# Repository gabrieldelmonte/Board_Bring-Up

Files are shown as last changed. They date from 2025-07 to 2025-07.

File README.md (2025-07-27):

# Board Bring-Up Project

A microcontroller-based embedded system project featuring real-time monitoring, alarm management, and multi-language support using the PIC18F4550 microcontroller.

## Project Overview

This project implements a comprehensive board bring-up system that combines multiple peripherals and sensors to create a monitoring and control system. The system features a state machine-based architecture with real-time clock functionality, analog sensor monitoring, alarm management, and a user-friendly LCD interface.

## Features

### Core Functionality
- **Real-Time Clock (RTC)**: DS1307-based timekeeping with hour, minute, and second setting
- **Analog Monitoring**: ADC-based sensor reading with configurable alarm thresholds
- **Alarm System**: Dual-level alarm monitoring (high/low thresholds) with visual indicators
- **Multi-Language Support**: Interface available in 6 different languages
- **State Machine Architecture**: Robust navigation system between different operational modes

### Hardware Peripherals
- **LCD Display**: 16-character display for system information and menus
- **LED Control**: Visual feedback and alarm indication system
- **Button Interface**: Navigation and parameter adjustment controls
- **I2C Communication**: For RTC and DAC communication
- **PWM Output**: Pulse width modulation for analog output control
- **Serial Communication**: UART interface for debugging and external communication
- **DAC Output**: MCP4725-based digital-to-analog conversion

### System States
- **Menu**: Main navigation interface
- **Alarm Configuration**: Set high and low alarm thresholds
- **Language Selection**: Choose from 6 available languages
- **Time Setting**: Configure hours, minutes, and seconds
- **Warning Mode**: Alert state when alarm conditions are triggered

## Hardware Requirements

### Microcontroller
- **PIC18F4550** microcontroller
- **20 MHz** crystal oscillator
- Power supply and basic support components

### Peripherals
- **DS1307** Real-Time Clock module
- **MCP4725** Digital-to-Analog Converter
- **16x2 LCD Display** with HD44780 controller
- **LEDs** for status indication
- **Push buttons** for user interface
- **Analog sensor** (connected to ADC channel 0)

### Development Tools
- MPLAB X IDE or compatible PIC development environment
- XC8 compiler for PIC18 family
- Programmer/debugger (PICkit, ICD, etc.)

## Project Structure

```
Board_Bring-Up/
├── src/
│   ├── main.c              # Main application entry point
│   └── code/
│       ├── ADC.c           # Analog-to-Digital Converter functions
│       ├── button.c        # Button handling and debouncing
│       ├── DAC_MCP4725.c   # MCP4725 DAC communication
│       ├── delay.c         # Timing and delay functions
│       ├── event.c         # Event handling and system events
│       ├── I2C.c           # I2C communication protocol
│       ├── LCD.c           # LCD display control functions
│       ├── LED.c           # LED control and patterns
│       ├── output.c        # Output formatting and display
│       ├── PWM.c           # Pulse Width Modulation control
│       ├── RTC_DS1307.c    # Real-Time Clock functions
│       ├── serial.c        # UART serial communication
│       ├── stateMachine.c  # Main state machine implementation
│       ├── variables.c     # Global variable management
│       └── headers/        # Header files for all modules
├── hardware/               # KiCad PCB design files
├── diagrams/               # System architecture diagrams
└── docs/                   # Project documentation
```

## Getting Started

### Prerequisites
1. MPLAB X IDE installed
2. XC8 compiler for PIC18 family
3. PIC programmer/debugger
4. Assembled hardware board or prototyping setup

### Building the Project
1. Clone this repository:
   ```bash
   git clone https://github.com/your-username/Board_Bring-Up.git
   cd Board_Bring-Up
   ```

2. Open the project in MPLAB X IDE

3. Configure the project settings:
   - Select PIC18F4550 as target device
   - Set XC8 as the compiler
   - Configure programmer/debugger

4. Build the project:
   - Click "Build" or use Ctrl+F11
   - Resolve any compilation errors

5. Program the microcontroller:
   - Connect your programmer
   - Click "Make and Program Device"

### Hardware Setup
1. Connect the LCD display to PORTD and control pins (RA2, RA3)
2. Wire the DS1307 RTC to the I2C bus (RC3/SCL, RC4/SDA)
3. Connect analog sensor to AN0 (RA0)
4. Wire push buttons for navigation
5. Connect LEDs for status indication
6. Ensure proper power supply (5V for PIC18F4550)

## Usage

### Navigation
- **Base Button**: Return to main menu from any state
- **Left/Right Buttons**: Navigate between menu options
- **Up/Down Buttons**: Adjust values in configuration modes

### Setting Alarms
1. Navigate to alarm configuration states
2. Use up/down buttons to adjust high and low thresholds
3. System will trigger warnings when sensor readings exceed limits

### Time Configuration
1. Access time setting modes through menu navigation
2. Adjust hours, minutes, and seconds individually
3. Changes are automatically saved to RTC

### Language Selection
- Navigate to language menu
- Choose from 6 available language options
- Interface will update to selected language

## Configuration

### System Parameters
Key configuration options in `defines.h`:
- `FREQ`: System frequency (20 MHz)
- `NUMBER_LANGUAGES`: Available languages (6)
- `MAX_ADC_VALUE`: Maximum ADC reading (1000)
- `MIN_ADC_VALUE`: Minimum ADC reading (0)

### Pin Assignments
- **LCD Data**: PORTD (RD0-RD7)
- **LCD Control**: RA2 (RS), RA3 (EN)
- **I2C**: RC3 (SCL), RC4 (SDA)
- **ADC Input**: RA0 (AN0)
- **LED Outputs**: Configurable in LED.c

## Additional Resources

- [PIC18F4550 Datasheet](https://www.microchip.com/en-us/product/PIC18F4550)
- [DS1307 RTC Datasheet](https://datasheets.maximintegrated.com/en/ds/DS1307.pdf)
- [MCP4725 DAC Datasheet](https://ww1.microchip.com/downloads/en/DeviceDoc/22039d.pdf)
- PCB design files are available in the `hardware/` directory

## License

This project is licensed under the terms specified in the LICENSE file.

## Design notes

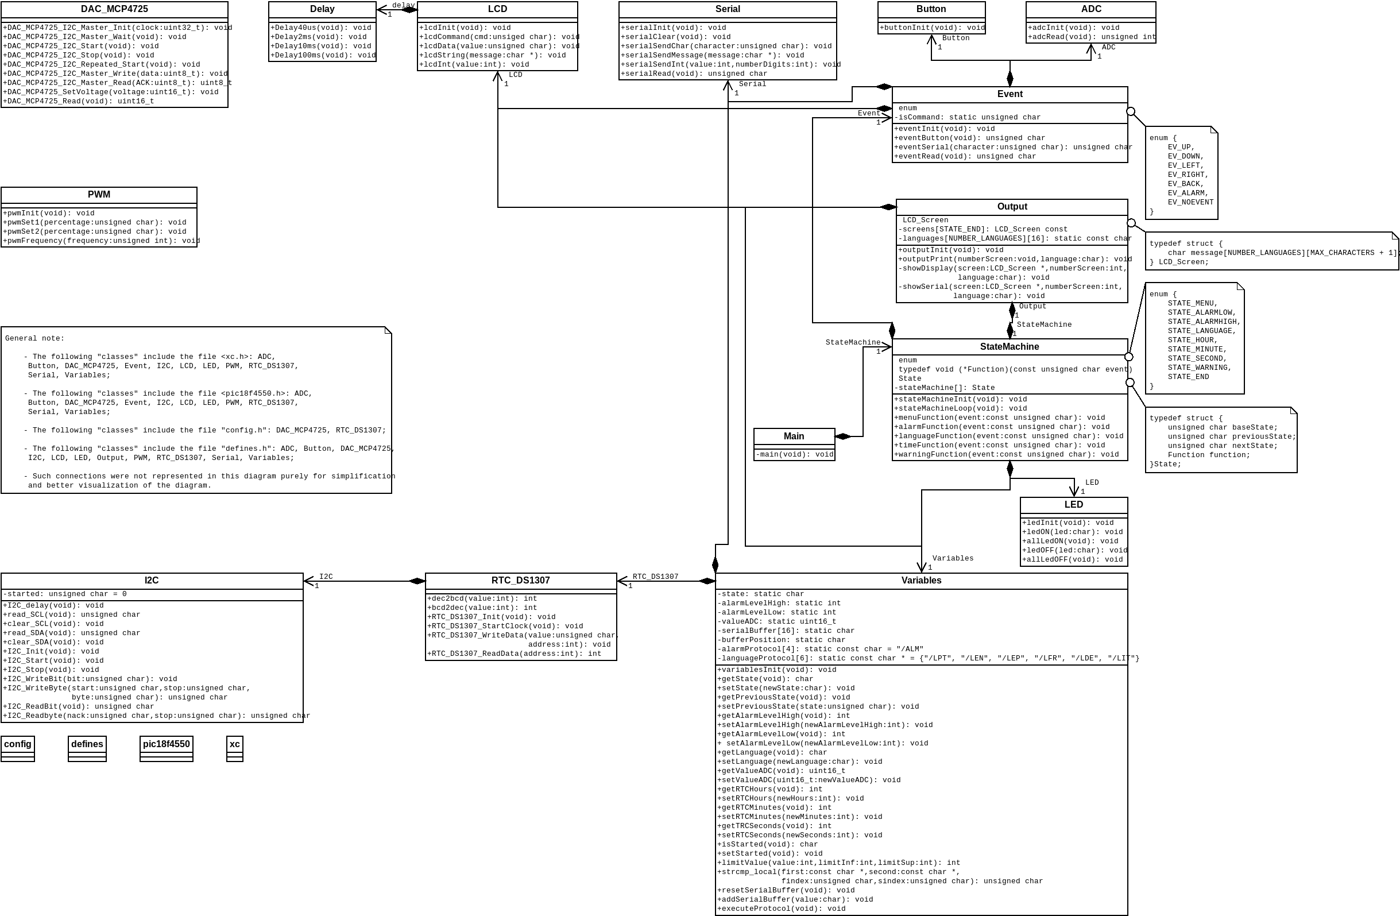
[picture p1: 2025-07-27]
diagrams/PBLE02_classes.png

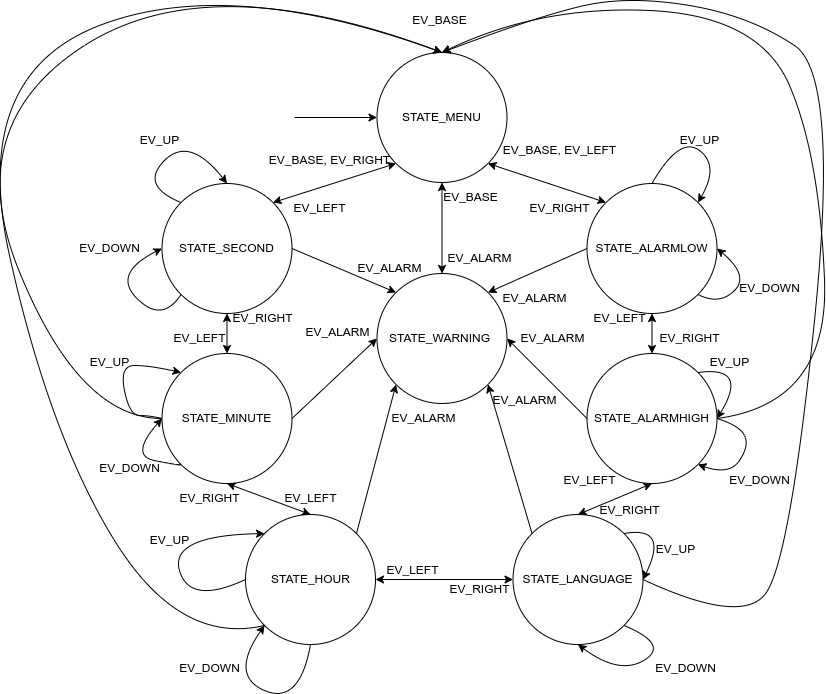
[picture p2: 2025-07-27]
diagrams/PBLE02_states.png

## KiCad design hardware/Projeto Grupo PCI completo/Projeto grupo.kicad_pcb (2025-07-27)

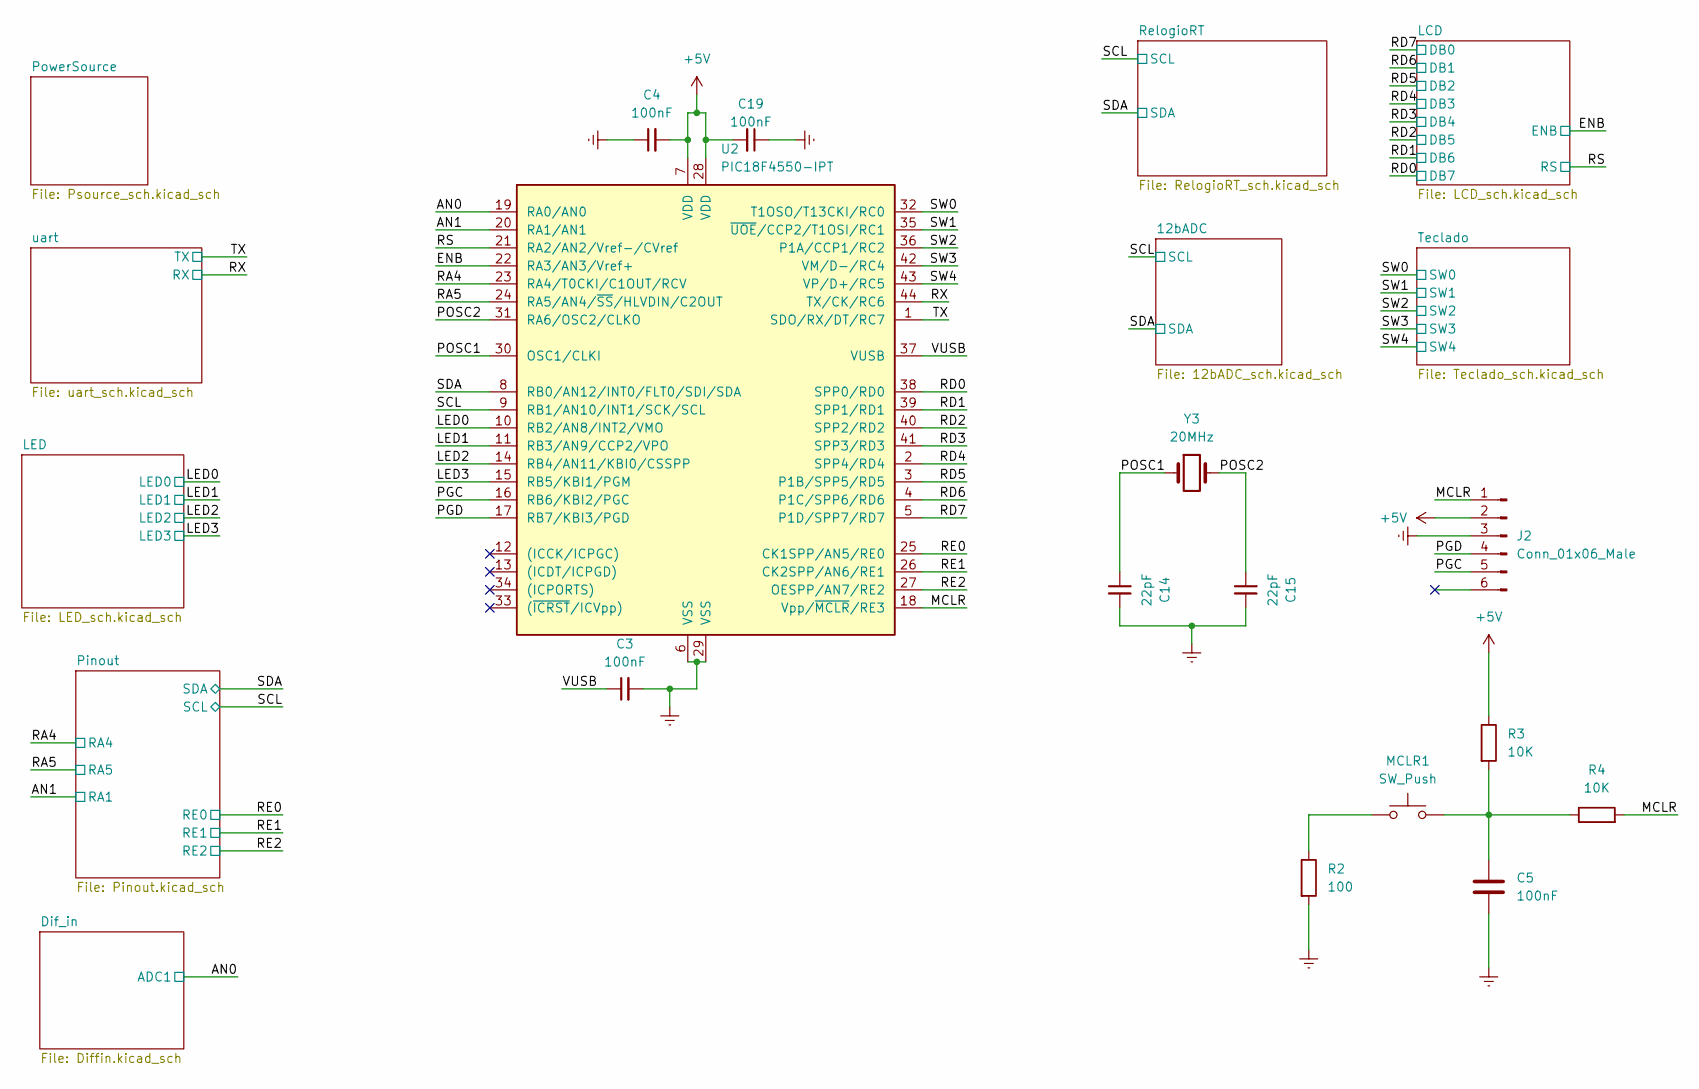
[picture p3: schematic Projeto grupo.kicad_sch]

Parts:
C3, C4, C5, C19: 100nF; C_0805_2012Metric
C14, C15: 22pF; C_0805_2012Metric
J2: Conn_01x06_Male; PinHeader_1x06_P2.54mm_Vertical
MCLR1: SW_Push; SW_PUSH_6mm
R2: 100; R_0805_2012Metric
R3, R4: 10K; R_0805_2012Metric
U2: PIC18F4550-IPT; TQFP-44_10x10mm_P0.8mm
Y3: 20MHz; Crystal_HC49-4H_Vertical

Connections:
+5V: C4.2, C19.2, J2.2, R3.1, U2.7 (VDD), U2.28 (VDD); also elsewhere on the board
/AN0: U2.19 (RA0/AN0); also elsewhere on the board
/AN1: U2.20 (RA1/AN1); also elsewhere on the board
/ENB: U2.22 (RA3/AN3/Vref+); also elsewhere on the board
/LED0: U2.10 (RB2/AN8/INT2/VMO); also elsewhere on the board
/LED1: U2.11 (RB3/AN9/CCP2/VPO); also elsewhere on the board
/LED2: U2.14 (RB4/AN11/KBI0/CSSPP); also elsewhere on the board
/LED3: U2.15 (RB5/KBI1/PGM); also elsewhere on the board
/MCLR: J2.1, R4.2, U2.18 (Vpp/~MCLR/RE3)
/PGC: J2.5, U2.16 (RB6/KBI2/PGC)
/PGD: J2.4, U2.17 (RB7/KBI3/PGD)
/POSC1: C14.1, U2.30 (OSC1/CLKI), Y3.1
/POSC2: C15.1, U2.31 (RA6/OSC2/CLKO), Y3.2
/RA4: U2.23 (RA4/T0CKI/C1OUT/RCV); also elsewhere on the board
/RA5: U2.24 (RA5/AN4/~SS/HLVDIN/C2OUT); also elsewhere on the board
/RD0: U2.38 (SPP0/RD0); also elsewhere on the board
/RD1: U2.39 (SPP1/RD1); also elsewhere on the board
/RD2: U2.40 (SPP2/RD2); also elsewhere on the board
/RD3: U2.41 (SPP3/RD3); also elsewhere on the board
/RD4: U2.2 (SPP4/RD4); also elsewhere on the board
/RD5: U2.3 (P1B/SPP5/RD5); also elsewhere on the board
/RD6: U2.4 (P1C/SPP6/RD6); also elsewhere on the board
/RD7: U2.5 (P1D/SPP7/RD7); also elsewhere on the board
/RE0: U2.25 (CK1SPP/AN5/RE0); also elsewhere on the board
/RE1: U2.26 (CK2SPP/AN6/RE1); also elsewhere on the board
/RE2: U2.27 (OESPP/AN7/RE2); also elsewhere on the board
/RS: U2.21 (RA2/AN2/Vref-/CVref); also elsewhere on the board
/RX: U2.44 (TX/CK/RC6); also elsewhere on the board
/SCL: U2.9 (RB1/AN10/INT1/SCK/SCL); also elsewhere on the board
/SDA: U2.8 (RB0/AN12/INT0/FLT0/SDI/SDA); also elsewhere on the board
/SW0: U2.32 (T1OSO/T13CKI/RC0); also elsewhere on the board
/SW1: U2.35 (~UOE/CCP2/T1OSI/RC1); also elsewhere on the board
/SW2: U2.36 (P1A/CCP1/RC2); also elsewhere on the board
/SW3: U2.42 (VM/D-/RC4); also elsewhere on the board
/SW4: U2.43 (VP/D+/RC5); also elsewhere on the board
/TX: U2.1 (SDO/RX/DT/RC7); also elsewhere on the board
/VUSB: C3.1, U2.37 (VUSB)
Earth: C3.2, C4.1, C5.2, C14.2, C15.2, C19.1, J2.3, R2.2, U2.6 (VSS), U2.29 (VSS); also elsewhere on the board
unnamed 39: C5.1, MCLR1.2, R3.2, R4.1; also elsewhere on the board
unnamed 60: MCLR1.1, R2.1; also elsewhere on the board

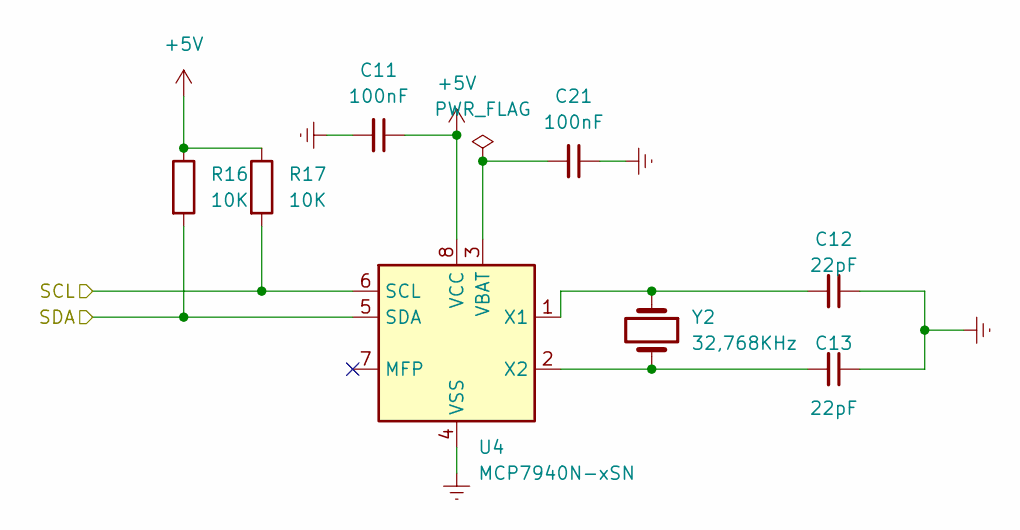
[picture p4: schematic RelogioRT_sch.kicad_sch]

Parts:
C11, C21: 100nF; C_0805_2012Metric
C12, C13: 22pF; C_0805_2012Metric
R16, R17: 10K; R_0805_2012Metric
U4: MCP7940N-xSN
Y2: 32,768KHz; AB38T32768KHZ

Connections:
+5V: C11.1, R16.1, R17.1, U4.8 (VCC); also elsewhere on the board
/SCL: R17.2, U4.6 (SCL); also elsewhere on the board
/SDA: R16.2, U4.5 (SDA); also elsewhere on the board
Earth: C11.2, C12.1, C13.1, C21.1, U4.4 (VSS); also elsewhere on the board
unnamed: C12.2, U4.1 (X1), Y2.1
unnamed: C13.2, U4.2 (X2), Y2.2
unnamed: C21.2, U4.3 (VBAT)

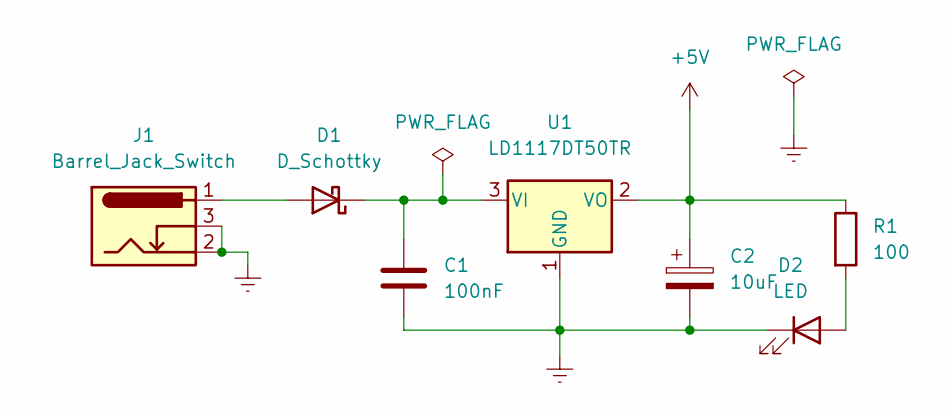
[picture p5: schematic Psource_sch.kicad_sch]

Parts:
C1: 100nF; C_0805_2012Metric
C2: 10uF; CP_EIA-3216-12_Kemet-S
D1: D_Schottky; D_SOD-123
D2: LED; LED_1206_3216Metric_Pad1.42x1.75mm_HandSolder
J1: Barrel_Jack_Switch; BarrelJack_Horizontal
R1: 100; R_0805_2012Metric
U1: LD1117DT50TR; ATPAK-2

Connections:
+5V: C2.1, R1.1, U1.2 (VO); also elsewhere on the board
Earth: C1.2, C2.2, D2.1 (K), J1.2, J1.3, U1.1 (GND); also elsewhere on the board
unnamed: C1.1, D1.1 (K), U1.3 (VI)
unnamed: D1.2 (A), J1.1
unnamed: D2.2 (A), R1.2

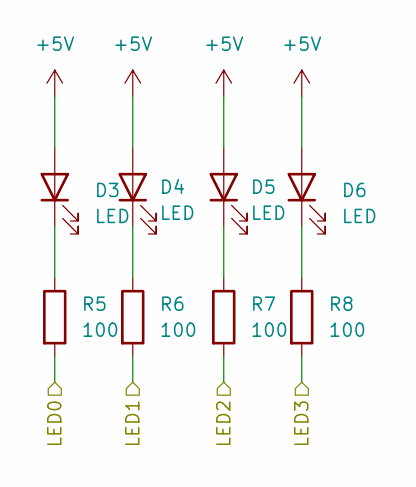
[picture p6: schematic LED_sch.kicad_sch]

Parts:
D3, D4, D5, D6: LED; LED_1206_3216Metric_Pad1.42x1.75mm_HandSolder
R5, R6, R7, R8: 100; R_0805_2012Metric

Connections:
+5V: D3.2 (A), D4.2 (A), D5.2 (A), D6.2 (A); also elsewhere on the board
/LED0: R5.2; also elsewhere on the board
/LED1: R6.2; also elsewhere on the board
/LED2: R7.2; also elsewhere on the board
/LED3: R8.2; also elsewhere on the board
unnamed: D3.1 (K), R5.1
unnamed: D4.1 (K), R6.1
unnamed: D5.1 (K), R7.1
unnamed: D6.1 (K), R8.1

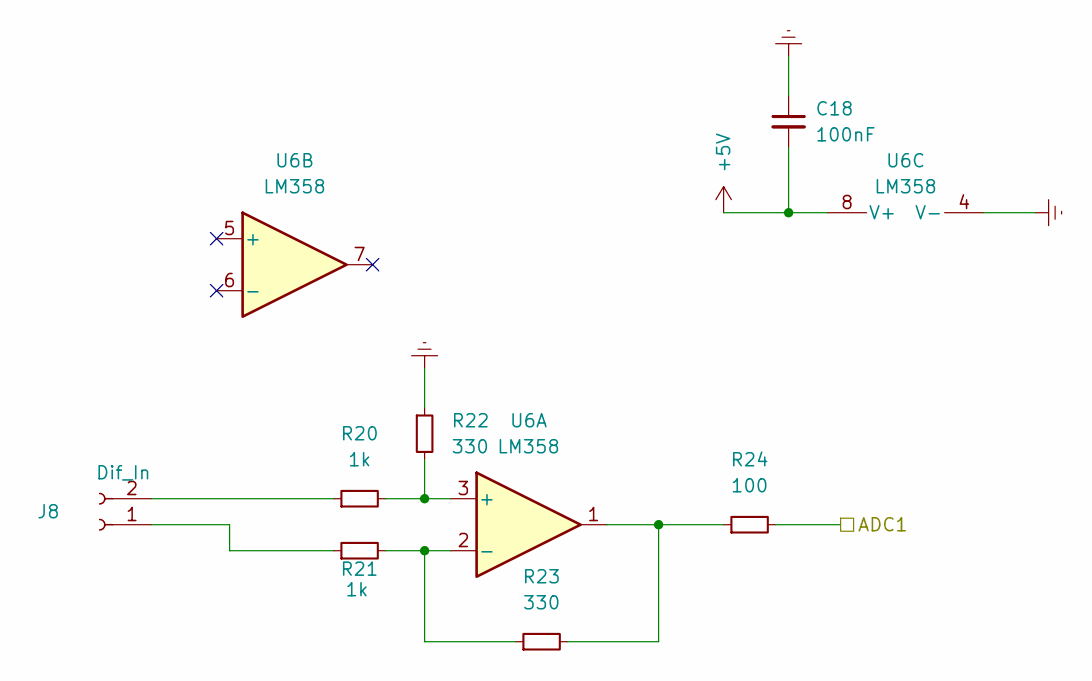
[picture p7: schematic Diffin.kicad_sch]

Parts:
C18: 100nF; C_0805_2012Metric
J8: Dif_In; On_Shore_Technology-OSTTA024163-0-0-MFG
R20, R21: 1k; R_0805_2012Metric
R22, R23: 330; R_0805_2012Metric
R24: 100; R_0805_2012Metric
U6: LM358

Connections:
+5V: C18.2, U6.8 (V+); also elsewhere on the board
/AN0: R24.2; also elsewhere on the board
Earth: C18.1, R22.1, U6.4 (V-); also elsewhere on the board
unnamed: J8.1, R21.1
unnamed: J8.2, R20.1
unnamed: R20.2, R22.2, U6.3 (+)
unnamed: R21.2, R23.1, U6.2 (-)
unnamed: R23.2, R24.1, U6.1

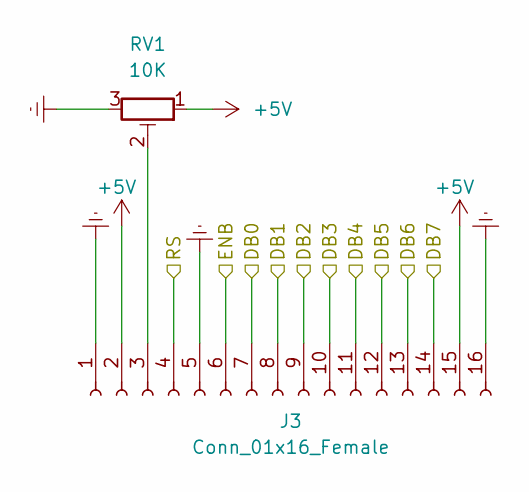
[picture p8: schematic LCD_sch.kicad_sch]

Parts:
J3: Conn_01x16_Female; PinSocket_1x16_P2.54mm_Vertical
RV1: 10K; Potentiometer_Bourns_3296W_Vertical

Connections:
+5V: J3.2, J3.15, RV1.1; also elsewhere on the board
/ENB: J3.6; also elsewhere on the board
/RD0: J3.14; also elsewhere on the board
/RD1: J3.13; also elsewhere on the board
/RD2: J3.12; also elsewhere on the board
/RD3: J3.11; also elsewhere on the board
/RD4: J3.10; also elsewhere on the board
/RD5: J3.9; also elsewhere on the board
/RD6: J3.8; also elsewhere on the board
/RD7: J3.7; also elsewhere on the board
/RS: J3.4; also elsewhere on the board
Earth: J3.1, J3.5, J3.16, RV1.3; also elsewhere on the board
unnamed: J3.3, RV1.2

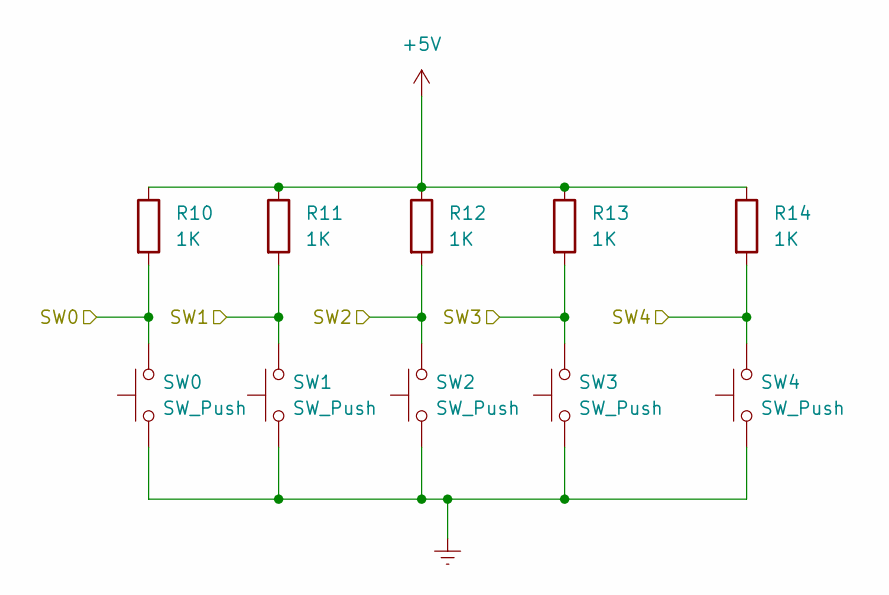
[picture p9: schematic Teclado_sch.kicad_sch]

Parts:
R10, R11, R12, R13, R14: 1K; R_0805_2012Metric
SW0, SW1, SW2, SW3, SW4: SW_Push; SW_PUSH_6mm

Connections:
+5V: R10.1, R11.1, R12.1, R13.1, R14.1; also elsewhere on the board
/SW0: R10.2, SW0.2; also elsewhere on the board
/SW1: R11.2, SW1.2; also elsewhere on the board
/SW2: R12.2, SW2.2; also elsewhere on the board
/SW3: R13.2, SW3.2; also elsewhere on the board
/SW4: R14.2, SW4.2; also elsewhere on the board
Earth: SW0.1, SW1.1, SW2.1, SW3.1, SW4.1; also elsewhere on the board

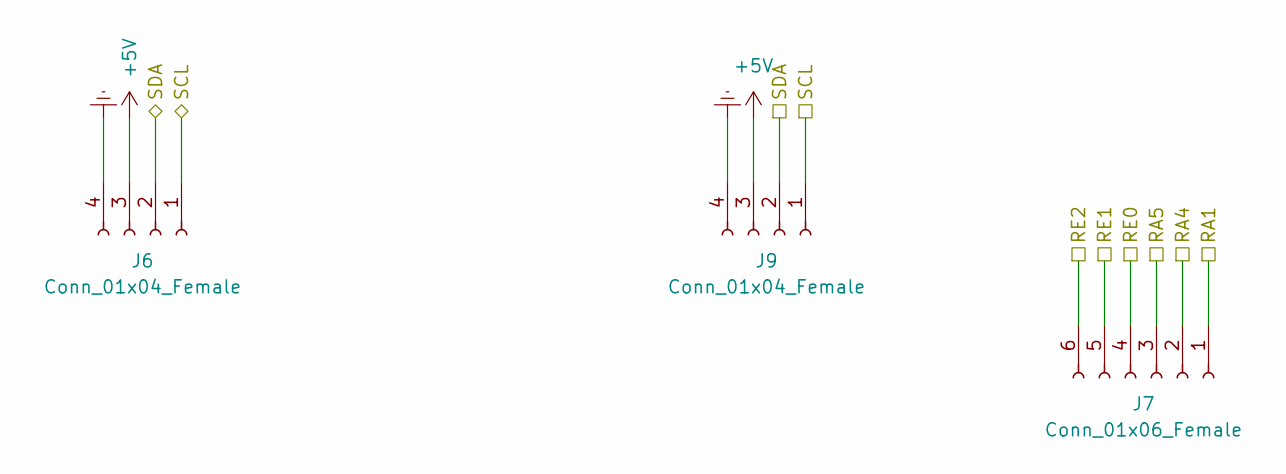
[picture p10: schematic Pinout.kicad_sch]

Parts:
J6, J9: Conn_01x04_Female; PinSocket_1x04_P2.54mm_Vertical
J7: Conn_01x06_Female; PinSocket_1x06_P2.54mm_Vertical

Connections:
+5V: J6.3, J9.3; also elsewhere on the board
/AN1: J7.1; also elsewhere on the board
/RA4: J7.2; also elsewhere on the board
/RA5: J7.3; also elsewhere on the board
/RE0: J7.4; also elsewhere on the board
/RE1: J7.5; also elsewhere on the board
/RE2: J7.6; also elsewhere on the board
/SCL: J6.1, J9.1; also elsewhere on the board
/SDA: J6.2, J9.2; also elsewhere on the board
Earth: J6.4, J9.4; also elsewhere on the board

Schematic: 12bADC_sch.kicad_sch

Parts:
C16: 100nF; C_0805_2012Metric
C17: 10uF; CP_EIA-3216-12_Kemet-S
J5: adcout; On_Shore_Technology-OSTTA024163-0-0-MFG
R15: 100; R_0805_2012Metric
U5: MCP4725A0T-E/CH; SOT-23-6

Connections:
+5V: C16.2, C17.1, U5.3 (VDD); also elsewhere on the board
/SCL: U5.5 (SCL); also elsewhere on the board
/SDA: U5.4 (SDA); also elsewhere on the board
Earth: C16.1, C17.2, J5.2, U5.2 (VSS), U5.6 (A0); also elsewhere on the board
unnamed: J5.1, R15.2
unnamed: R15.1, U5.1 (VOUT)

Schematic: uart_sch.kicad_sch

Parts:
C6, C7: 22pF; C_0805_2012Metric
C8, C9, C20: 100nF; C_0805_2012Metric
C10: 220nF; C_0805_2012Metric
J4: USB_A; USB_B_Lumberg_2411_02_Horizontal
R9: 10K; R_0805_2012Metric
U3: MCP2200-I-SO; SOIC-20W_7.5x12.8mm_P1.27mm
Y1: 12MHz; Crystal_HC49-4H_Vertical

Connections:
+5V: C9.2, R9.1, U3.1 (VDD); also elsewhere on the board
/RX: U3.12 (RX); also elsewhere on the board
/TX: U3.10 (TX); also elsewhere on the board
Earth: C6.2, C7.2, C8.1, C9.1, C10.2, C20.1, J4.4 (GND), U3.20 (VSS); also elsewhere on the board
unnamed: C6.1, U3.2 (OSC1), Y1.2
unnamed: C7.1, U3.3 (OSC2), Y1.1
unnamed: C8.2, R9.2, U3.4 (RST)
unnamed: C10.1, U3.17 (V_USB)
unnamed: C20.2, J4.1 (VBUS)
unnamed: J4.2 (D-), U3.18 (D-)
unnamed: J4.3 (D+), U3.19 (D+)

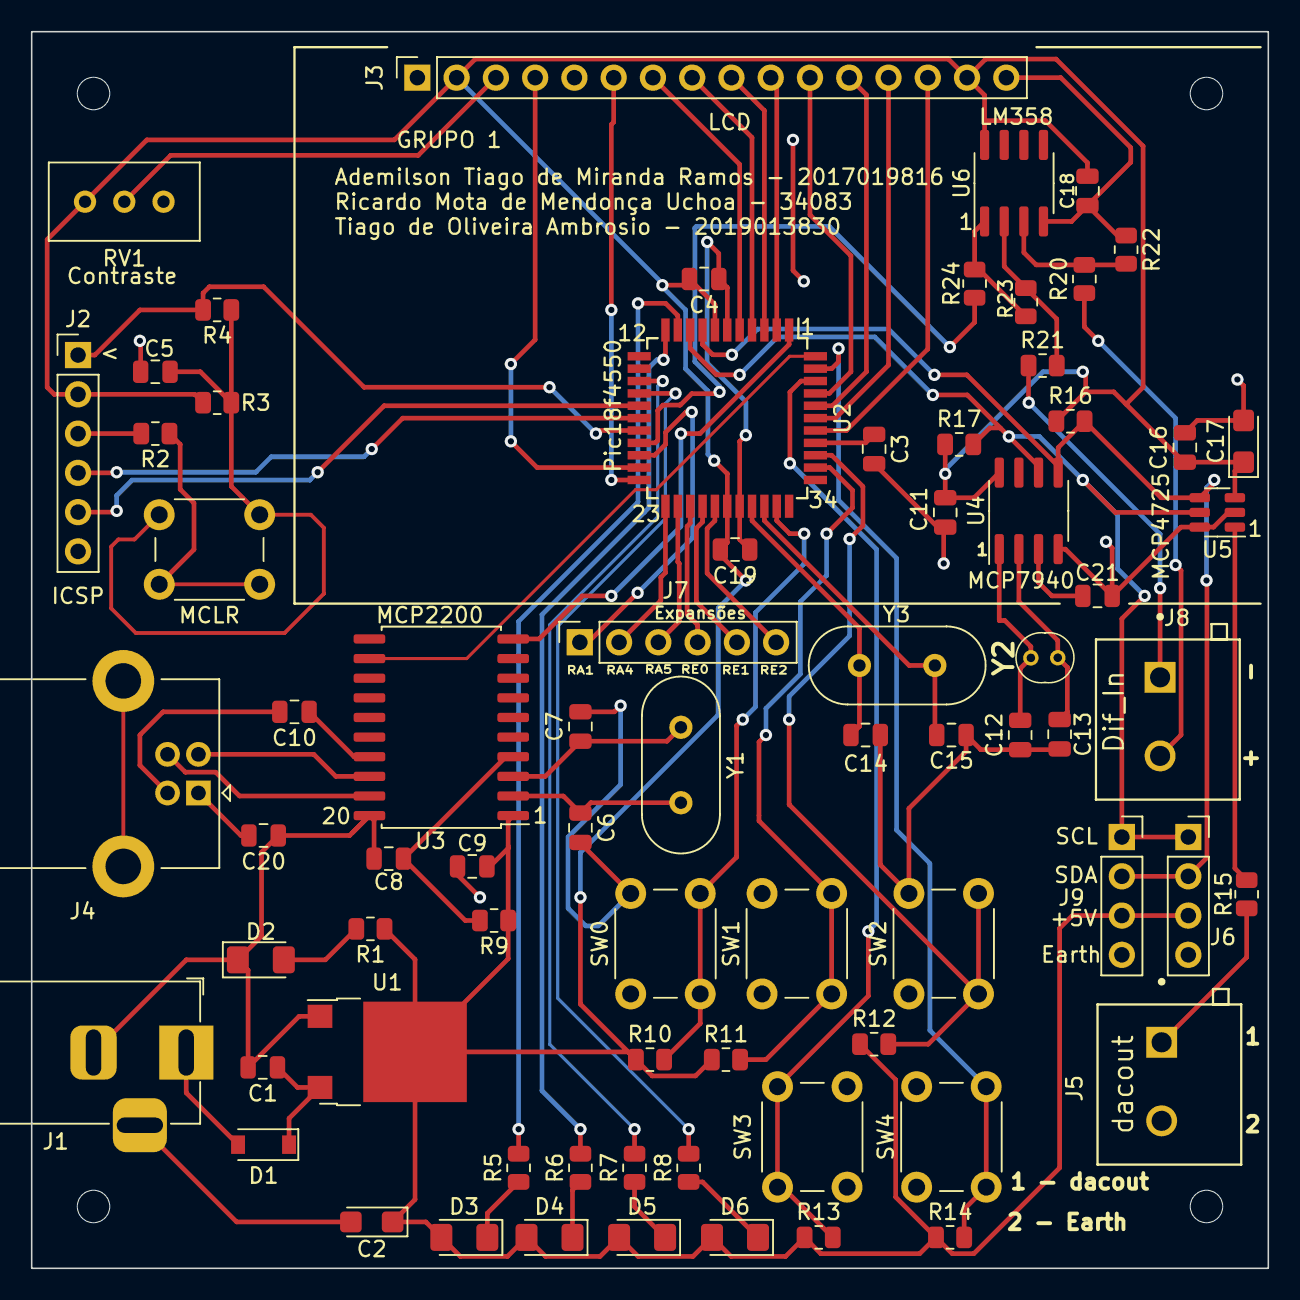
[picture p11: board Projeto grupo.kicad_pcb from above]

Board: 2 copper layers, 80.0 x 80.0 mm, 74 parts (0 on the bottom side), 65 nets.

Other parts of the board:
MCLR: SW_Push; SW_PUSH_6mm

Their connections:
unnamed 39: MCLR.2; also elsewhere on the board
unnamed 60: MCLR.1; also elsewhere on the board

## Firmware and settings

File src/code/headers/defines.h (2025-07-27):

#ifndef DEFINES_H
#define DEFINES_H

    #define PIC18F4550

    #define FREQ 20000000

    #define SPEED 25

    #define NUMBER_LANGUAGES 6

    #define MAX_CHARACTERS 16

    #define MAX_STRING_LENGTH 15

    #define MIN_ADC_VALUE 0000
    #define MAX_ADC_VALUE 1000

	#define BitSet(arg,bit) ((arg) |= (1<<bit))
	#define BitClr(arg,bit) ((arg) &= ~(1<<bit)) 
	#define BitFlp(arg,bit) ((arg) ^= (1<<bit)) 
	#define BitTst(arg,bit) ((arg) & (1<<bit))

#endif /* DEFINES_H */

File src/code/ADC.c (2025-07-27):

#include <xc.h>
#include <pic18f4550.h>
#include "headers/defines.h"
#include "headers/ADC.h"

 void adcInit(void) {
	BitSet(TRISA, 0);    // Set the RA0 as input
	ADCON0 = 0b00000001; // Select the Channel 0
	ADCON1 = 0b00001110; // Just AN0 is analog and the reference is based on VSS/VDD
	ADCON2 = 0b10101010; // Time of conversion: 12 TAD, FOSC/32
    return;
}

 unsigned int adcRead(void) {
	unsigned int valueRead;
	ADCON0 |= 0b00000010;      // Initialize the conversion
    while (BitTst(ADCON0, 1)); // Wait to finish
	valueRead = ADRESH ;       // Read the register
	valueRead <<= 8;
	valueRead += ADRESL;       // Read the register
	return valueRead;
}
